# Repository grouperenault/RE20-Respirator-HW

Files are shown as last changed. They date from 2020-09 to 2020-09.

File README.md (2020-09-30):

# RE20-Respirator-HW

All the files in this directory (and its subdirectories) are subject to
the CERN-OHL-S v2 licence.

Copyright Renault SAS 2020.

This source describes Open Hardware and is licensed under the CERN-OHL-S v2.
You may redistribute and modify this documentation and make products
using it under the terms of the CERN-OHL-S v2 (https:/cern.ch/cern-ohl).

This documentation is distributed WITHOUT ANY EXPRESS OR IMPLIED
WARRANTY, INCLUDING OF MERCHANTABILITY, SATISFACTORY QUALITY
AND FITNESS FOR A PARTICULAR PURPOSE. Please see the CERN-OHL-S v2
for applicable conditions.

This repository contains the Design files for the CAD and Electronic elements 
of the RE20-Respirator project.

For a description of the project, please refer to the [Readme of the RE20-Respirator-SW project](https://github.com/grouperenault/RE20-Respirator-SW/blob/master/README.md).

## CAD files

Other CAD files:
01-CASING-V2.1x/CASING.CATProduct
01-CASING-V2.1x/M-034804_--_---_256155.CATPart
01-CASING-V2.1x/M-035808_--_---_256215.CATPart
01-CASING-V2.1x/M-036530_--_---_256219.CATPart
01-CASING-V2.1x/M-03664800_--_---_256156.CATPart
01-CASING-V2.1x/M-036804_--_---_256216.CATPart
01-CASING-V2.1x/M-036820_--_---_256218.CATPart
01-CASING-V2.1x/M-126-4943_--_---_256391.CATPart
01-CASING-V2.1x/M-237-435_--_---_256127.CATPart
01-CASING-V2.1x/M-302-3006_--_---_256133.CATPart
01-CASING-V2.1x/M-468-6327_--_---_256234.CATPart
01-CASING-V2.1x/M-504-4588_--_---_256230.CATPart
01-CASING-V2.1x/M-521655_--_---_256422.CATPart
01-CASING-V2.1x/M-7703002668_--_---_256677.CATPart
01-CASING-V2.1x/M-7703002820_--_---_256847.CATPart
01-CASING-V2.1x/M-7703011320_--_---_256382.CATPart
01-CASING-V2.1x/M-7703027504_--_---_256681.CATPart
01-CASING-V2.1x/M-7703033205_--_---_256309.CATPart
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

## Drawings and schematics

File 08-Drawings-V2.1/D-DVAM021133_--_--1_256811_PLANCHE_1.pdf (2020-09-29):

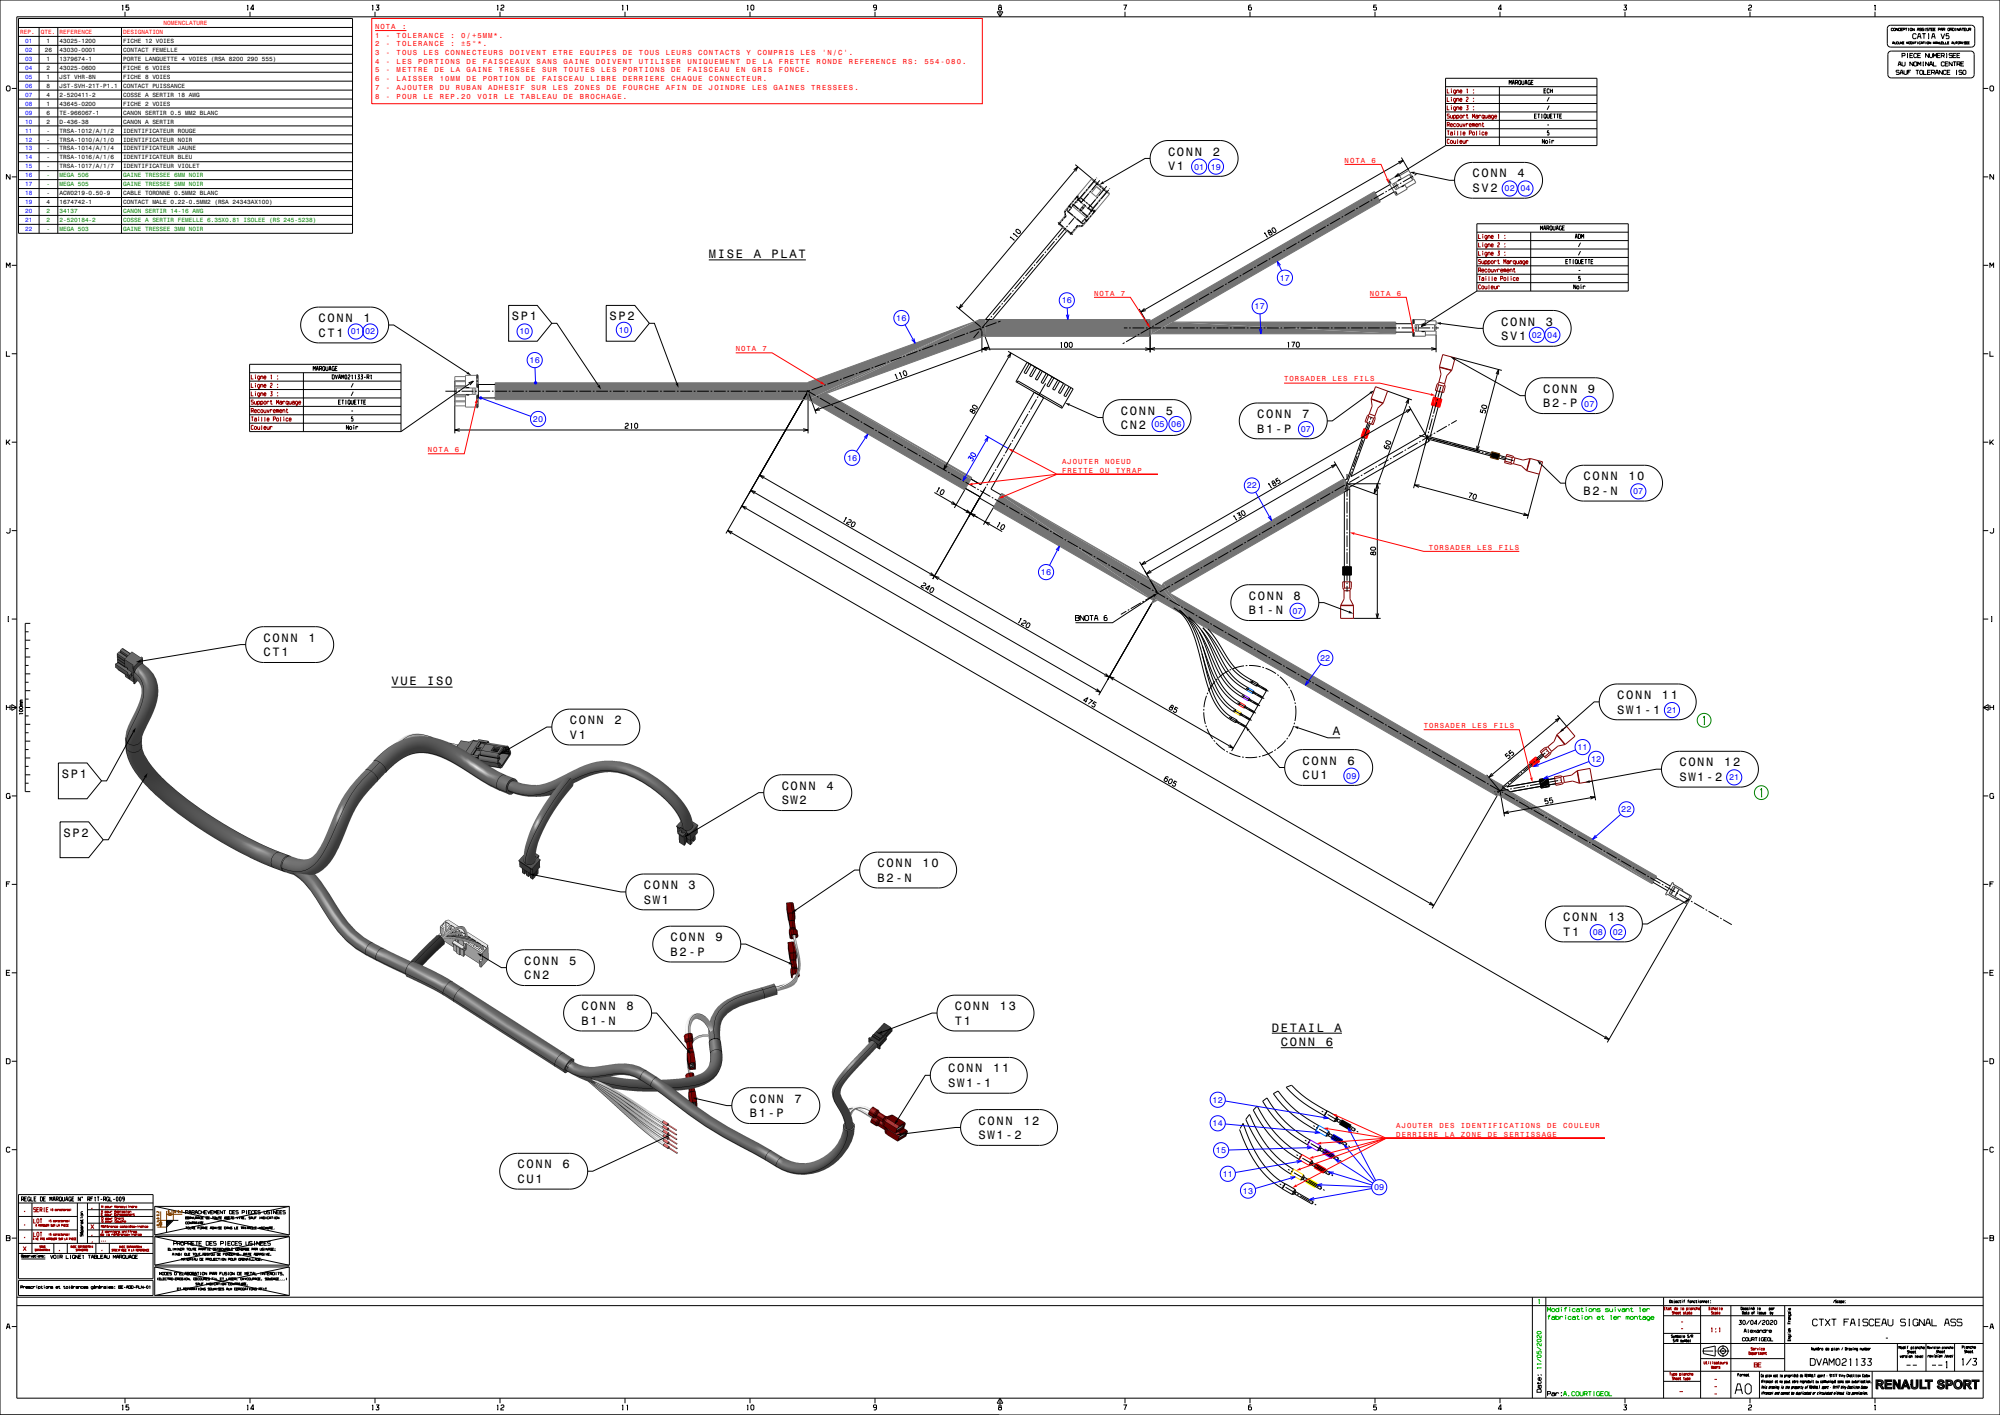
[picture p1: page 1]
MISE A PLAT; CONN 1; CONN 2; CONN 3; CONN 4; CONN 5 CN2 05 06; CONN 6; CONN 11 SW1-1 21; CONN 7 B1-P 07; CONN 9 B2-P 07; CONN 10 B2-N 07; CONN 13; CONN 12 SW1-2 21; CONN 8; NOTA 7; NOTA 6; DETAIL A CONN 6; VUE ISO; CONN 5; CONN 7; CONN 9; CONN 10; CONN 11; CONN 12

NOMENCLATURE | | NOTA : 1 - TOLERANCE : 0/+5MM*. 2 - TOLERANCE : ±5°*. 3 - TOUS LES CONNECTEURS DOIVENT ETRE EQUIPES DE TOUS LEURS CONTACTS Y COMPRIS LES 'N/C'. 4 - LES PORTIONS DE FAISCEAUX SANS GAINE DOIVENT UTILISER UNIQUEMENT DE LA FRETTE RONDE REFERENCE RS: 554-080. 5 - METTRE DE LA GAINE TRESSEE SUR TOUTES LES PORTIONS DE FAISCEAU EN GRIS FONCE. 6 - LAISSER 10MM DE PORTION DE FAISCEAU LIBRE DERRIERE CHAQUE CONNECTEUR. 7 - AJOUTER DU RUBAN ADHESIF SUR LES ZONES DE FOURCHE AFIN DE JOINDRE LES GAINES TRESSEES. 8 - POUR LE REP.20 VOIR LE TABLEAU DE BROCHAGE.

REP. | QTE. | REFERENCE | DESIGNATION
01 | 1 | 43025-1200 | FICHE 12 VOIES
02 | 26 | 43030-0001 | CONTACT FEMELLE
03 | 1 | 1379674-1 | PORTE LANGUETTE 4 VOIES (RSA 8200 290 555)
04 | 2 | 43025-0600 | FICHE 6 VOIES
05 | 1 | JST VHR-8N | FICHE 8 VOIES
06 | 8 | JST-SVH-21T-P1.1 | CONTACT PUISSANCE
07 | 4 | 2-520411-2 | COSSE A SERTIR 18 AWG
08 | 1 | 43645-0200 | FICHE 2 VOIES
09 | 6 | TE-966067-1 | CANON SERTIR 0.5 MM2 BLANC
10 | 2 | D-436-38 | CANON A SERTIR
11 | - | TRSA-1012/A/1/2 | IDENTIFICATEUR ROUGE
12 | - | TRSA-1010/A/1/0 | IDENTIFICATEUR NOIR
13 | - | TRSA-1014/A/1/4 | IDENTIFICATEUR JAUNE
14 | - | TRSA-1016/A/1/6 | IDENTIFICATEUR BLEU
15 | - | TRSA-1017/A/1/7 | IDENTIFICATEUR VIOLET
16 | - | MEGA 506 | GAINE TRESSEE 6MM NOIR
17 | - | MEGA 505 | GAINE TRESSEE 5MM NOIR
18 | - | ACW0219-0.50-9 | CABLE TORONNE 0.5MM2 BLANC
19 | 4 | 1674742-1 | CONTACT MALE 0.22-0.5MM2 (RSA 24343AX100)
20 | 2 | 34137 | CANON SERTIR 14-16 AWG
21 | 2 | 2-520184-2 | COSSE A SERTIR FEMELLE 6.35X0.81 ISOLEE (RS 245-5238)
22 | - | MEGA 503 | GAINE TRESSEE 3MM NOIR

NOTA 7 NOTA 6 16 17

TORSADER LES FILS

AJOUTER NOEUD
FRETTE OU TYRAP

AJOUTER DES IDENTIFICATIONS DE COULEUR
DERRIERE LA ZONE DE SERTISSAGE

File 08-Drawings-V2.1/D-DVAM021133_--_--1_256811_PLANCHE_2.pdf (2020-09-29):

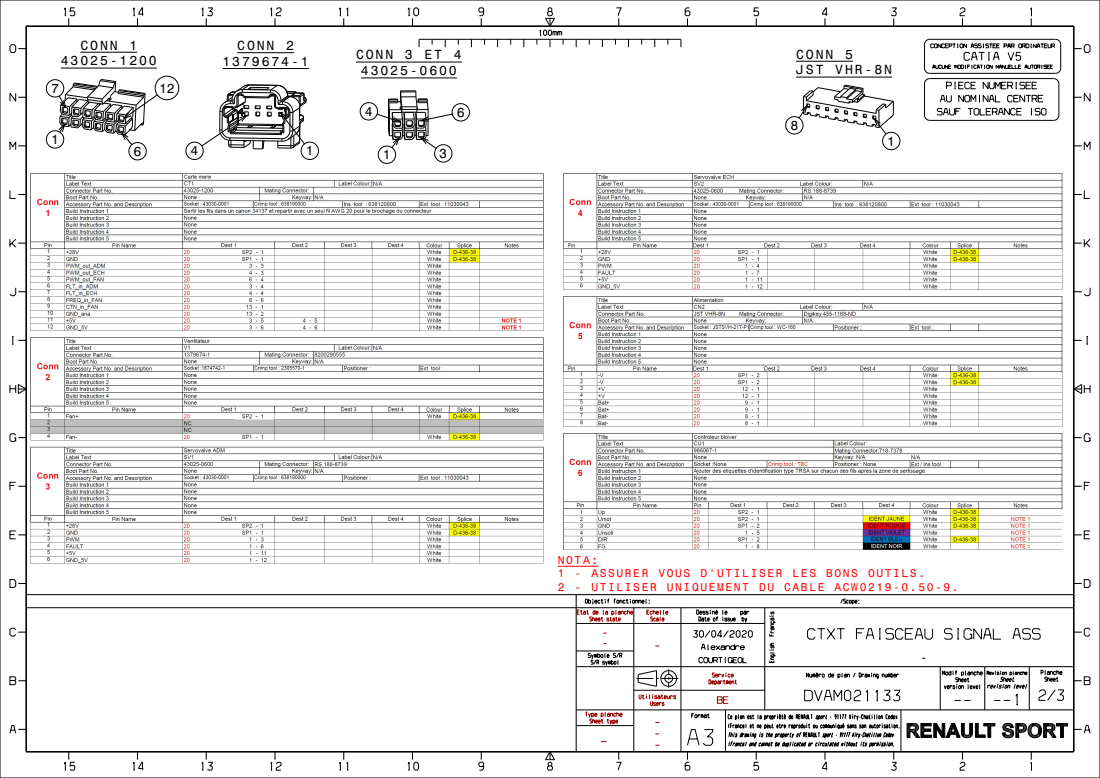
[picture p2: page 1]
CONN 3 ET 4; CONN 1; CONN 5 JST VHR-8N; CONN 2

NOTA:
1 - ASSURER VOUS D'UTILISER LES BONS OUTILS.
2 - UTILISER UNIQUEMENT DU CABLE ACW0219-0.50-9.

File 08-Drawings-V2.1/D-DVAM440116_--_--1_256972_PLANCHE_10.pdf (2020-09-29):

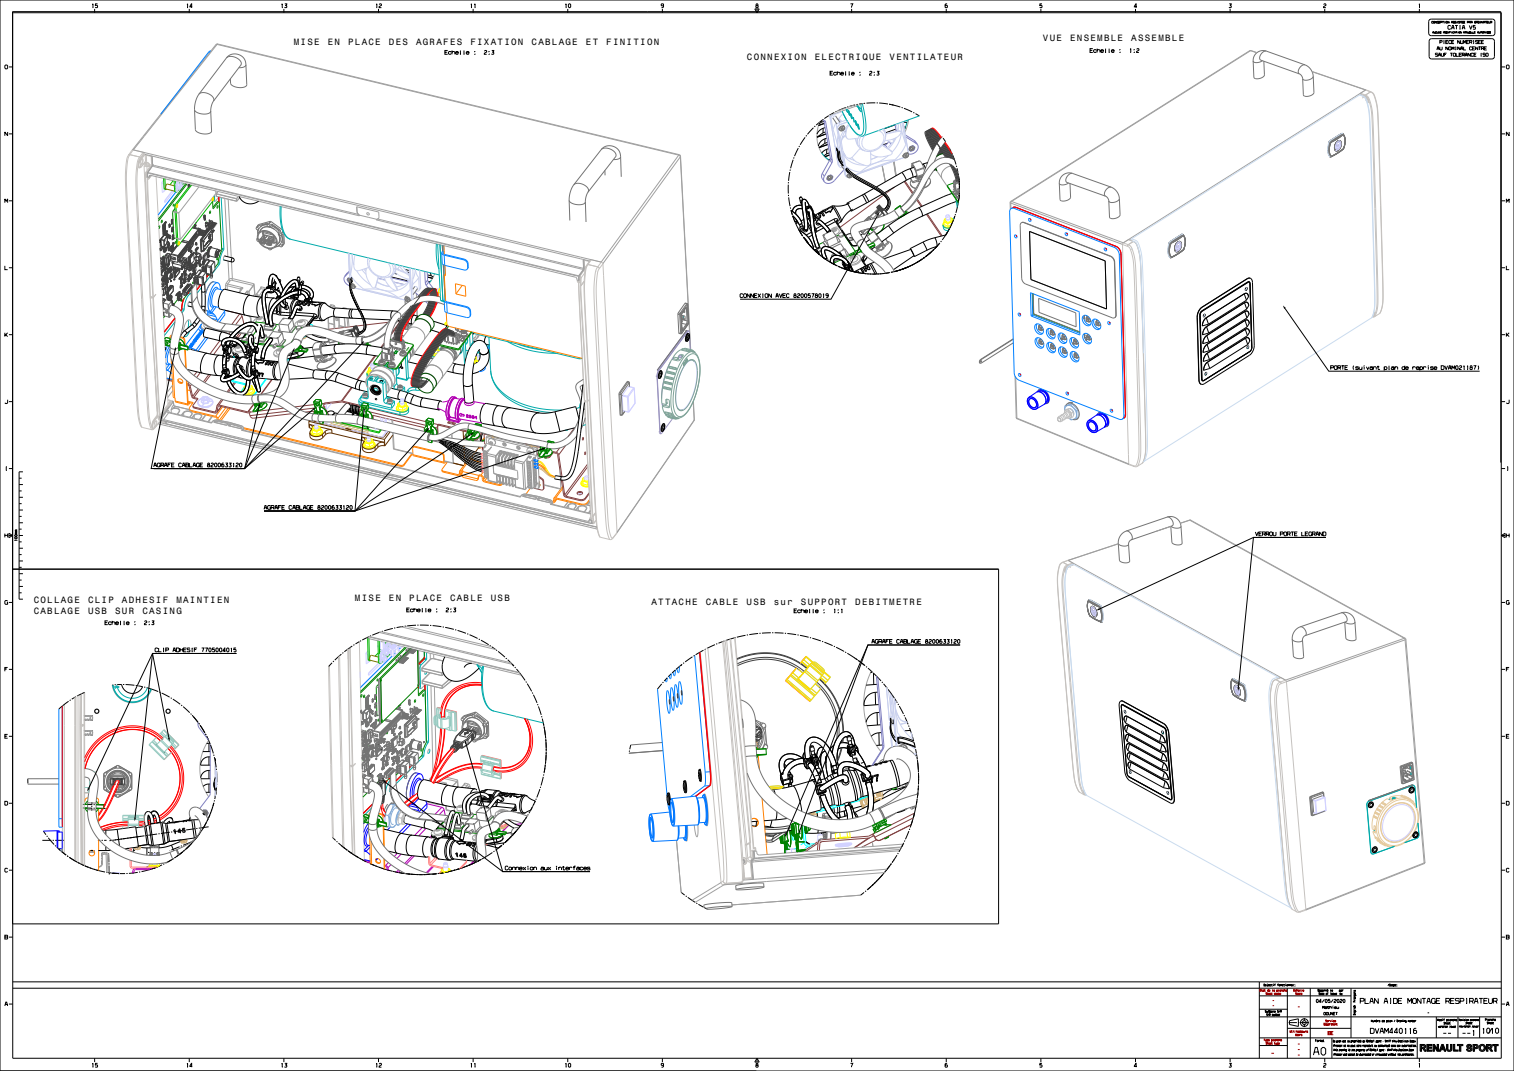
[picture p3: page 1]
COLLAGE CLIP ADHESIF MAINTIEN; MISE EN PLACE CABLE USB

VUE ENSEMBLE ASSEMBLE

MISE EN PLACE DES AGRAFES FIXATION CABLAGE ET FINITION

CONNEXION ELECTRIQUE VENTILATEUR

CABLAGE USB SUR CASING

ATTACHE CABLE USB sur SUPPORT DEBITMETRE

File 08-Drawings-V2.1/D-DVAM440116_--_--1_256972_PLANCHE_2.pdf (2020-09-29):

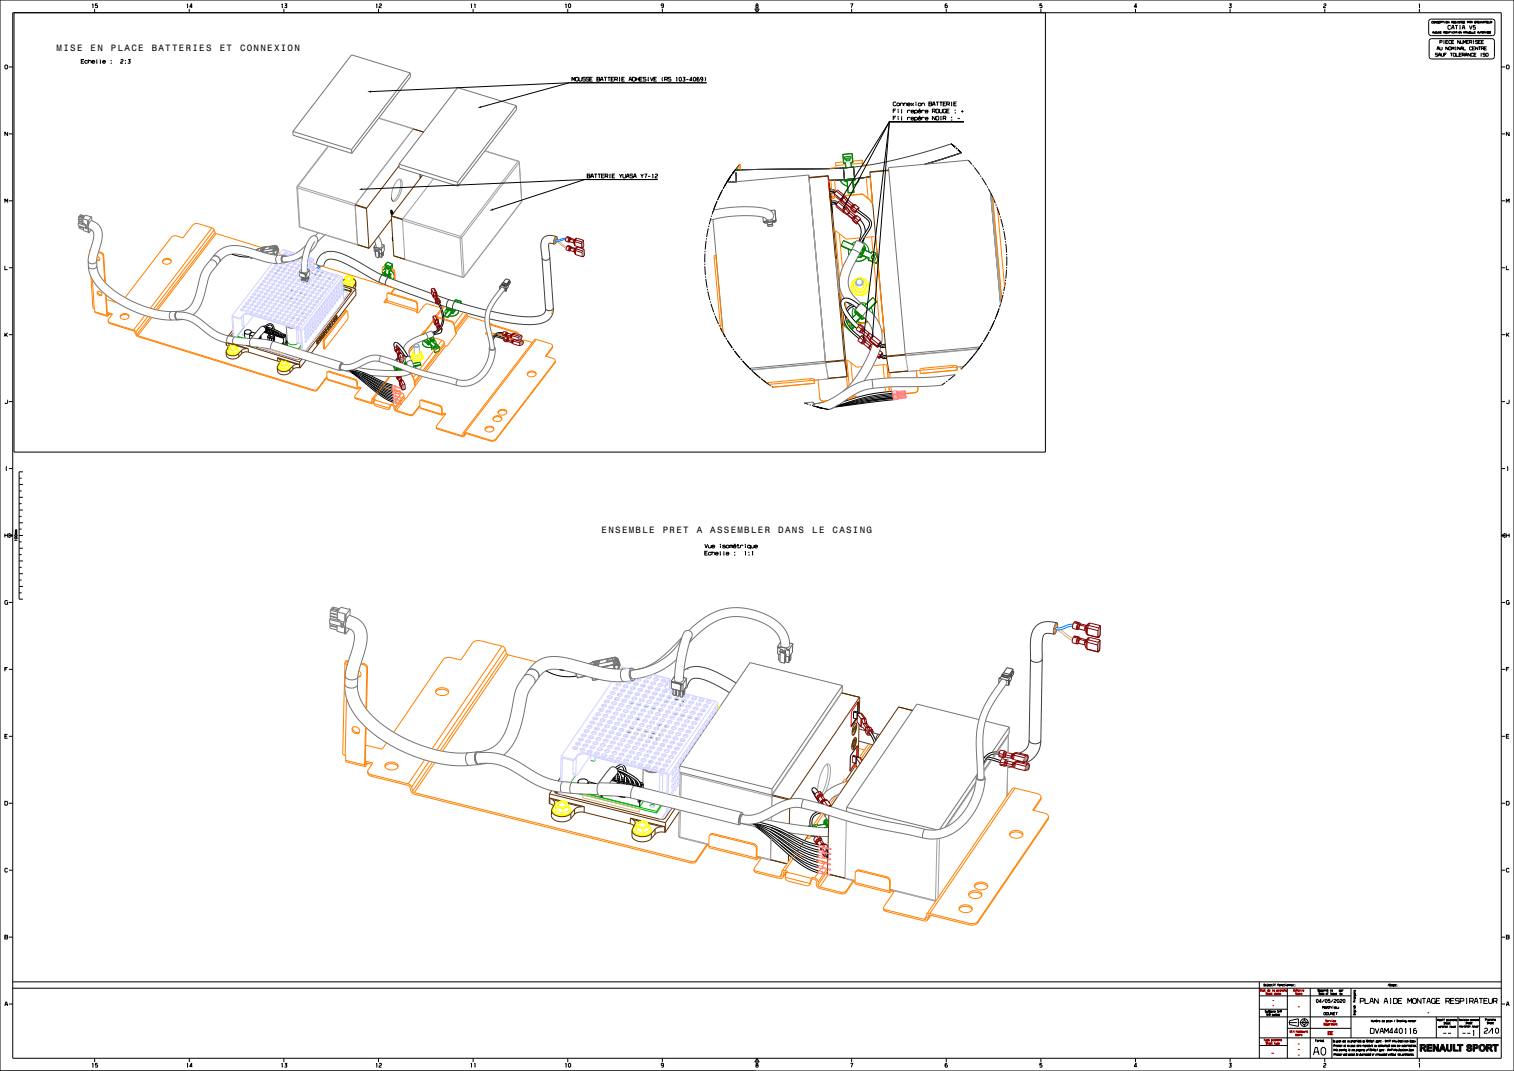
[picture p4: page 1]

MISE EN PLACE BATTERIES ET CONNEXION

ENSEMBLE PRET A ASSEMBLER DANS LE CASING

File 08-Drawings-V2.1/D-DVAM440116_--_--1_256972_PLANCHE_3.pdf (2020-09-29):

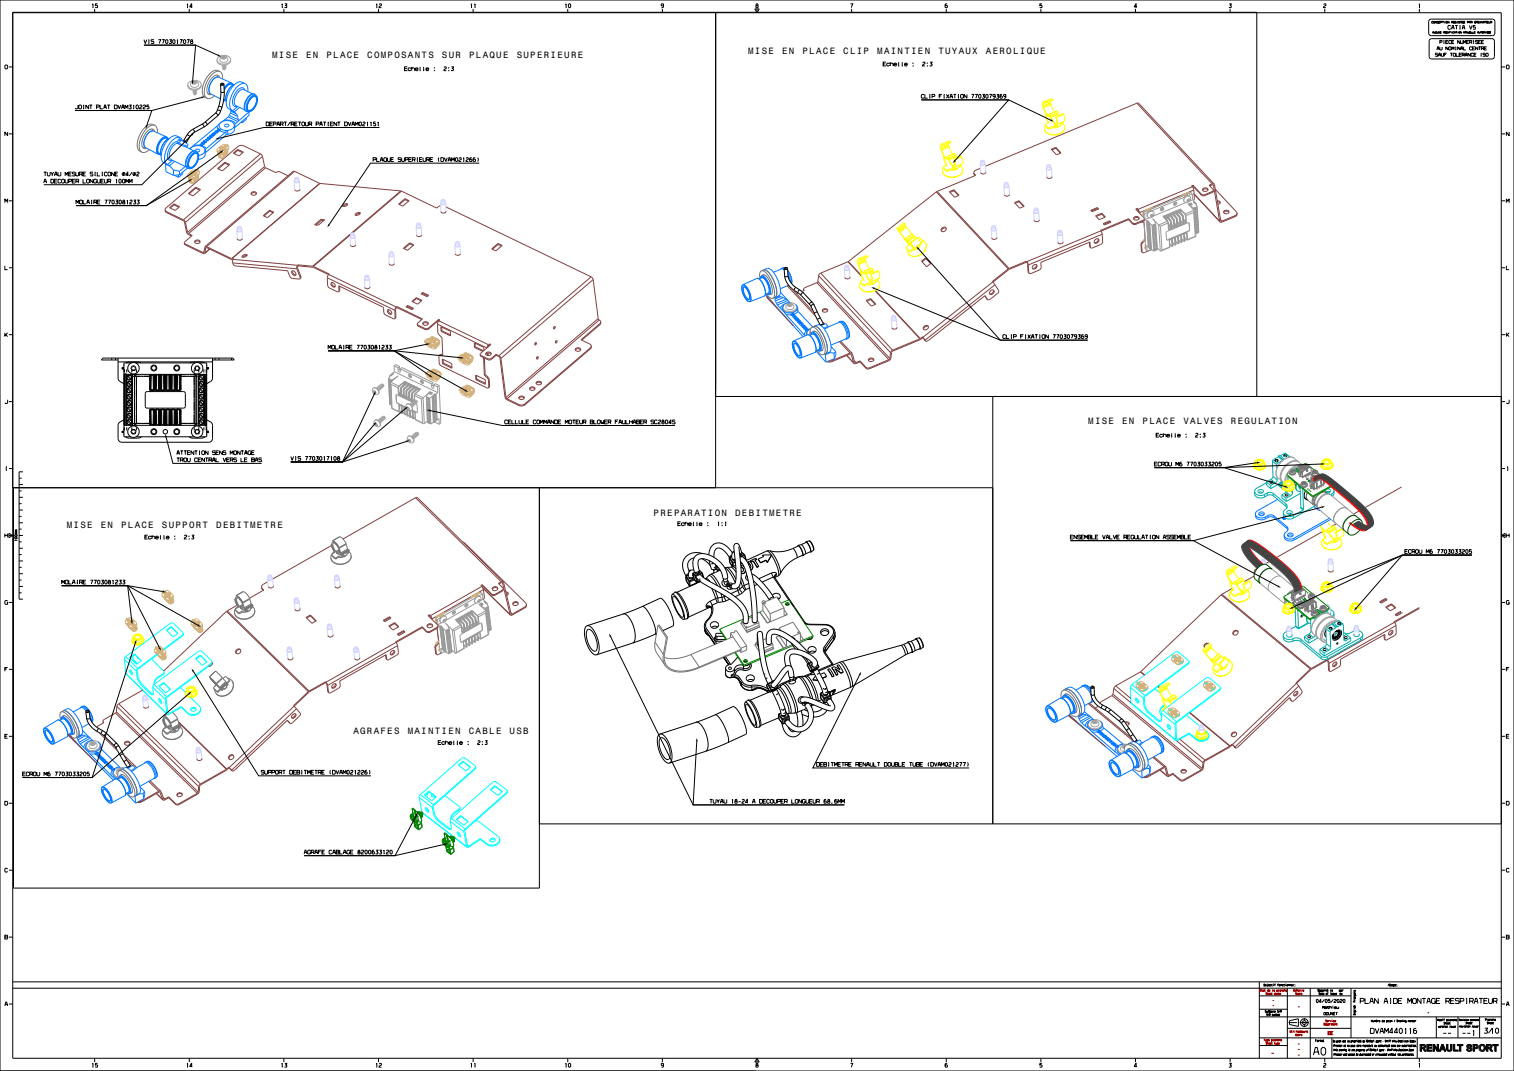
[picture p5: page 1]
PREPARATION DEBITMETRE

MISE EN PLACE CLIP MAINTIEN TUYAUX AEROLIQUE

MISE EN PLACE COMPOSANTS SUR PLAQUE SUPERIEURE

MISE EN PLACE VALVES REGULATION

MISE EN PLACE SUPPORT DEBITMETRE

AGRAFES MAINTIEN CABLE USB

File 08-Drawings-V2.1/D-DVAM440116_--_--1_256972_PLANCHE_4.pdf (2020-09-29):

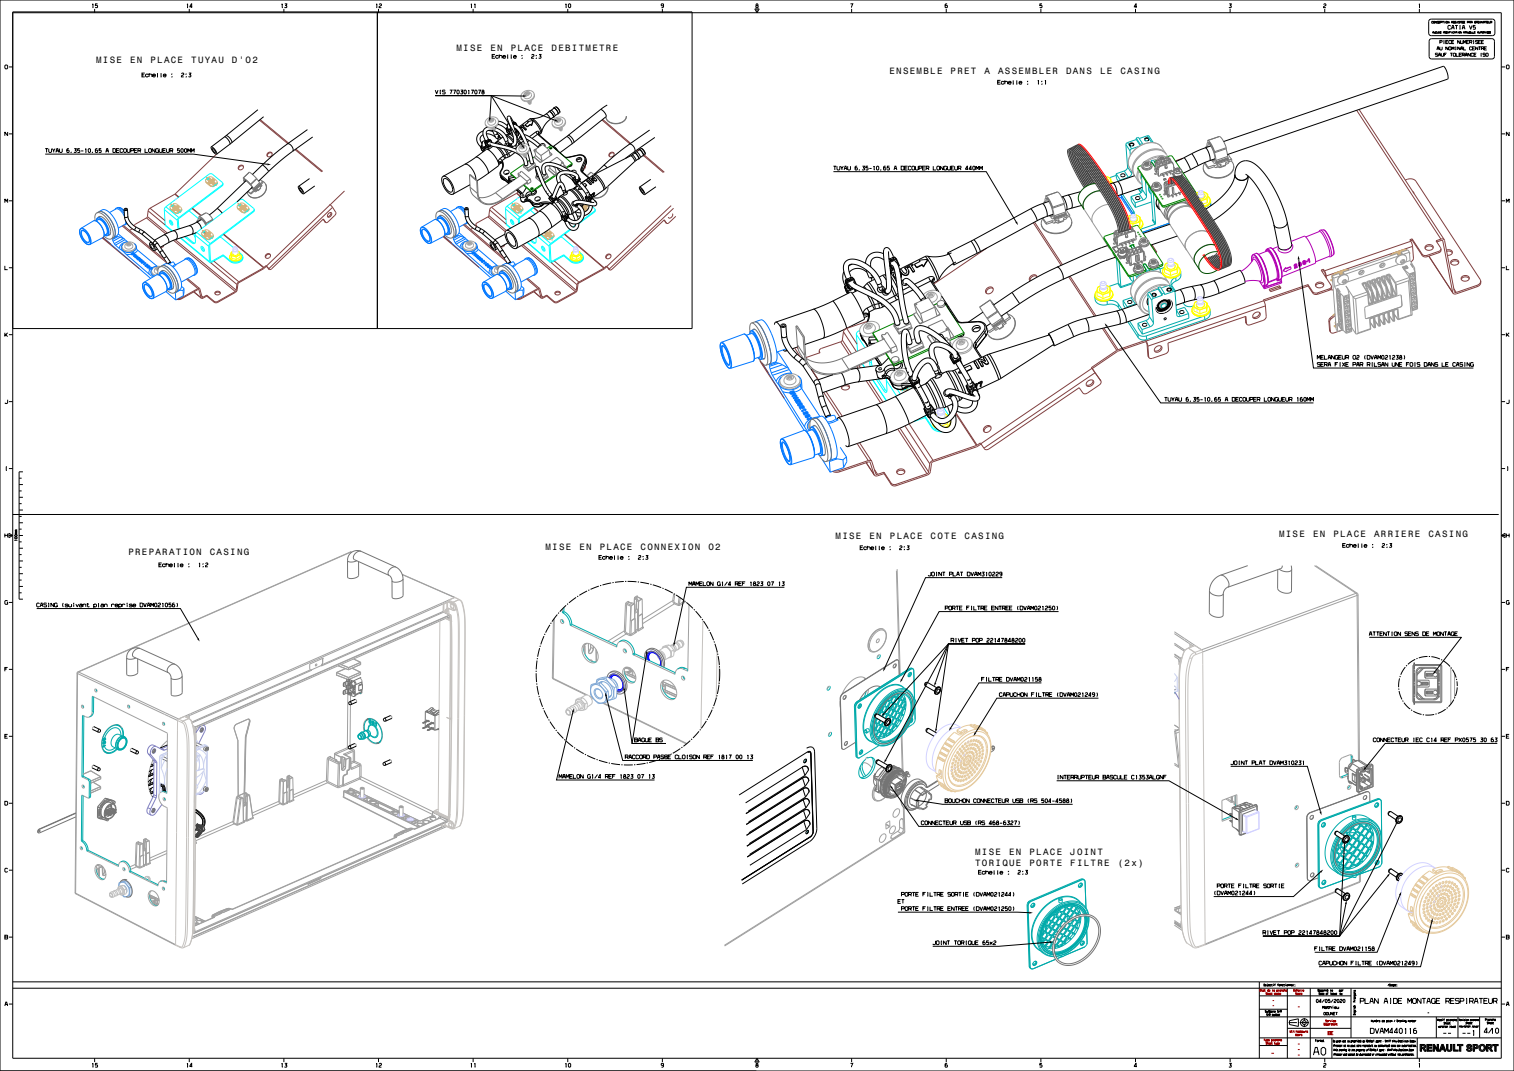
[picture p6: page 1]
PREPARATION CASING; MISE EN PLACE COTE CASING; MISE EN PLACE ARRIERE CASING

MISE EN PLACE DEBITMETRE

MISE EN PLACE TUYAU D'O2

ENSEMBLE PRET A ASSEMBLER DANS LE CASING

MISE EN PLACE CONNEXION O2

MISE EN PLACE JOINT
TORIQUE PORTE FILTRE (2x)

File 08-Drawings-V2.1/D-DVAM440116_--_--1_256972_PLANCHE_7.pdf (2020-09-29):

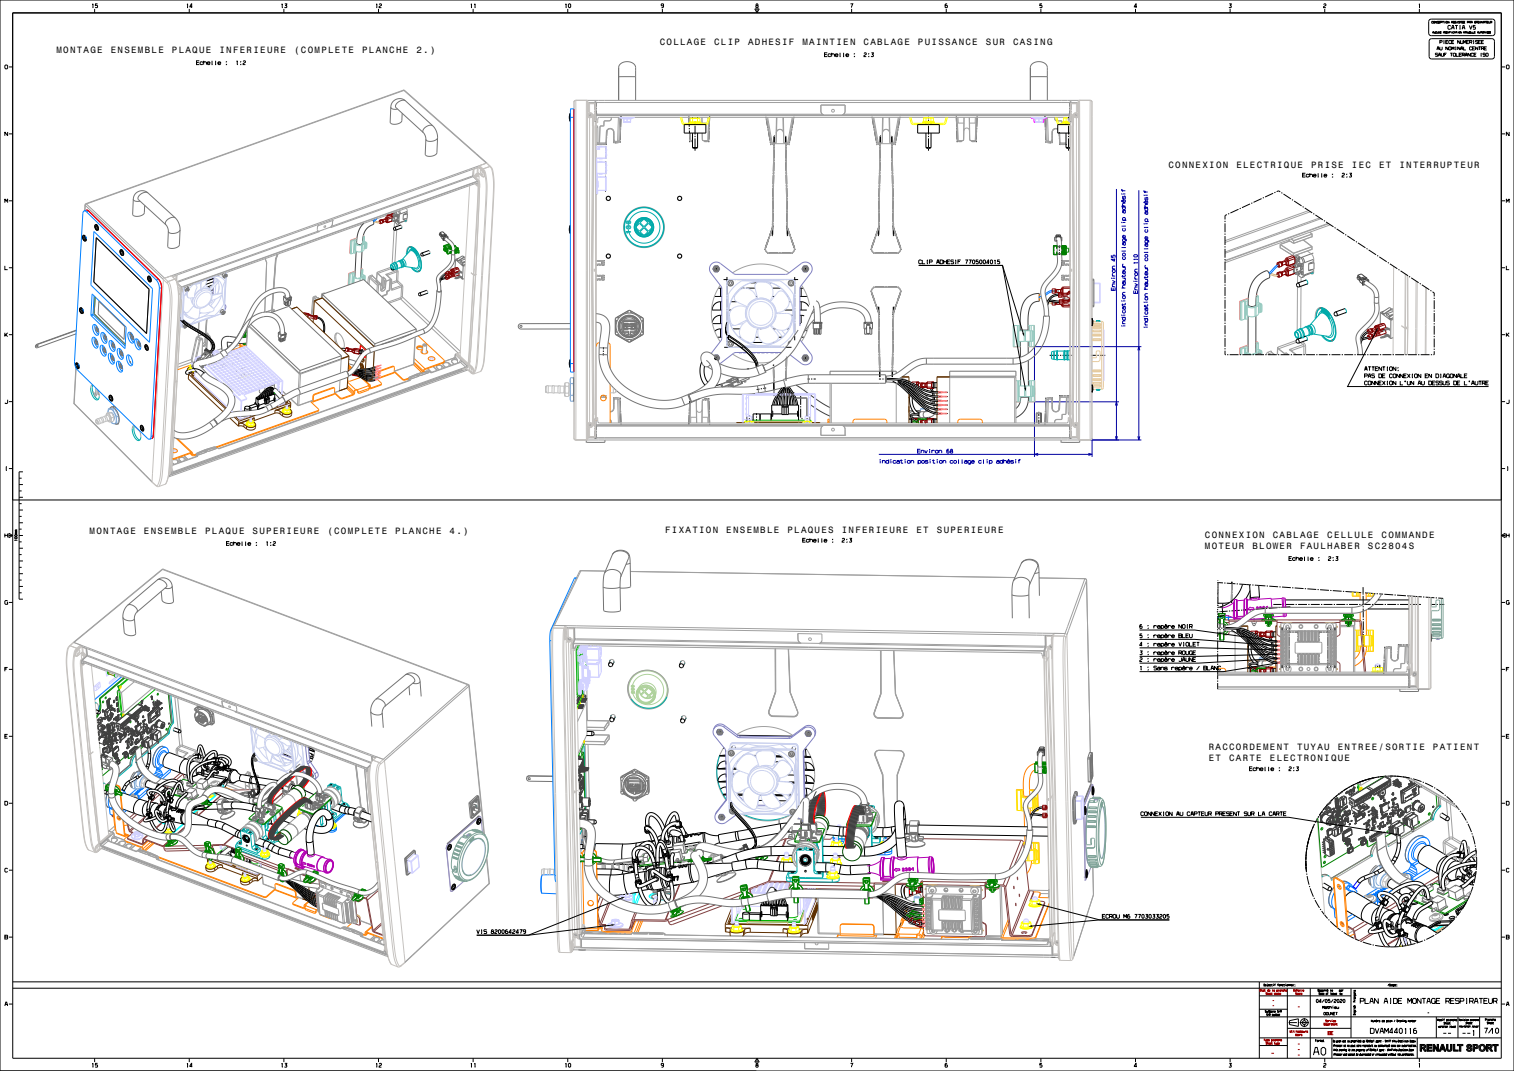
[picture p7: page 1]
MONTAGE ENSEMBLE PLAQUE SUPERIEURE (COMPLETE PLANCHE 4.); FIXATION ENSEMBLE PLAQUES INFERIEURE ET SUPERIEURE

COLLAGE CLIP ADHESIF MAINTIEN CABLAGE PUISSANCE SUR CASING

MONTAGE ENSEMBLE PLAQUE INFERIEURE (COMPLETE PLANCHE 2.)

CONNEXION ELECTRIQUE PRISE IEC ET INTERRUPTEUR

CONNEXION CABLAGE CELLULE COMMANDE
MOTEUR BLOWER FAULHABER SC2804S

RACCORDEMENT TUYAU ENTREE/SORTIE PATIENT
ET CARTE ELECTRONIQUE

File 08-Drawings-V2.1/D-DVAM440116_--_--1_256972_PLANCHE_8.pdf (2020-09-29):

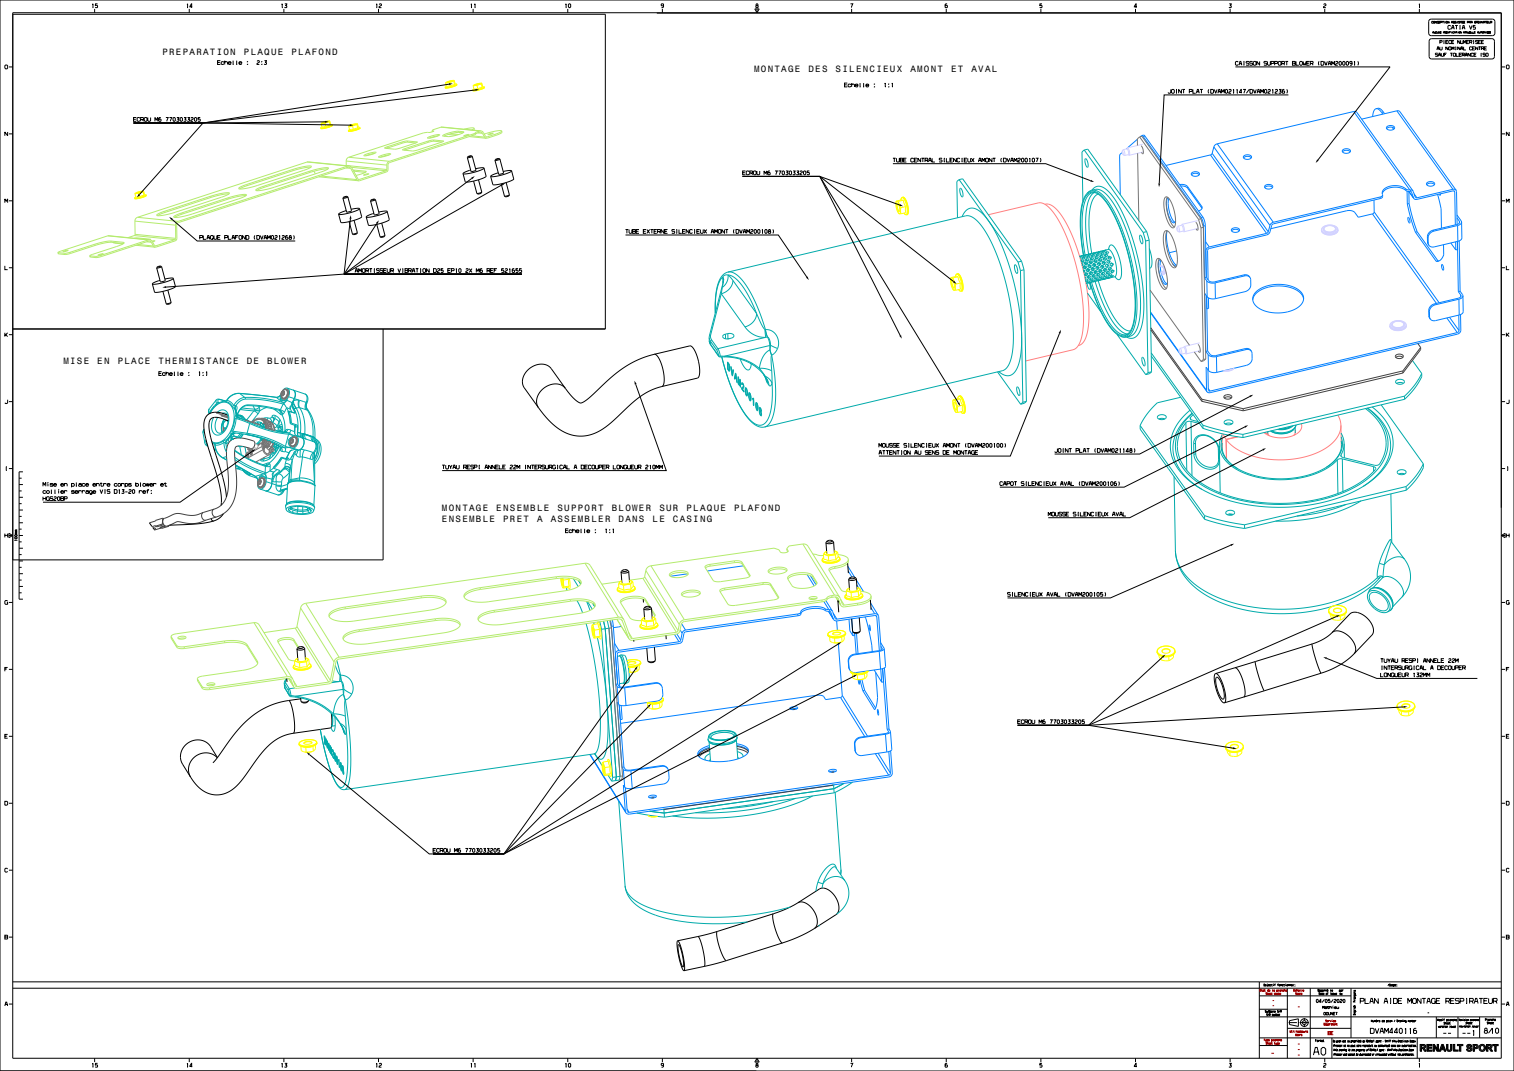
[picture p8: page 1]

PREPARATION PLAQUE PLAFOND

MONTAGE DES SILENCIEUX AMONT ET AVAL

MISE EN PLACE THERMISTANCE DE BLOWER

MONTAGE ENSEMBLE SUPPORT BLOWER SUR PLAQUE PLAFOND
ENSEMBLE PRET A ASSEMBLER DANS LE CASING

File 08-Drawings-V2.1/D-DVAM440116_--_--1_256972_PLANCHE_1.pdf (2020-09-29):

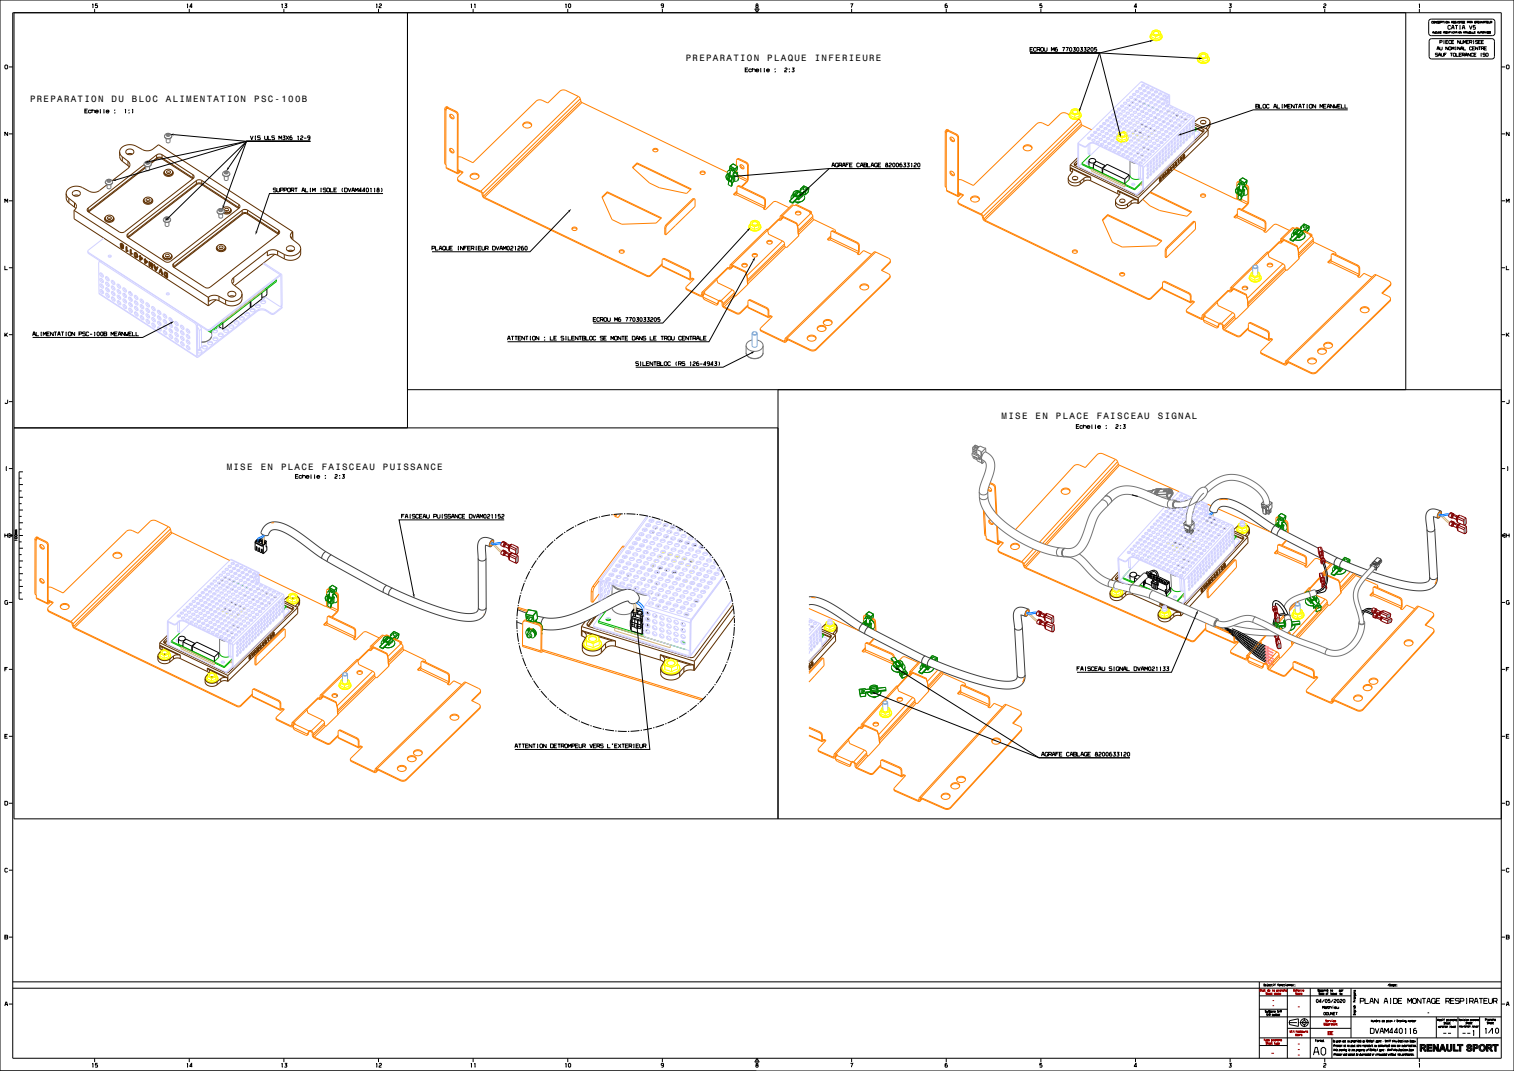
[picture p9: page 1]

PREPARATION PLAQUE INFERIEURE

PREPARATION DU BLOC ALIMENTATION PSC-100B

MISE EN PLACE FAISCEAU SIGNAL

MISE EN PLACE FAISCEAU PUISSANCE

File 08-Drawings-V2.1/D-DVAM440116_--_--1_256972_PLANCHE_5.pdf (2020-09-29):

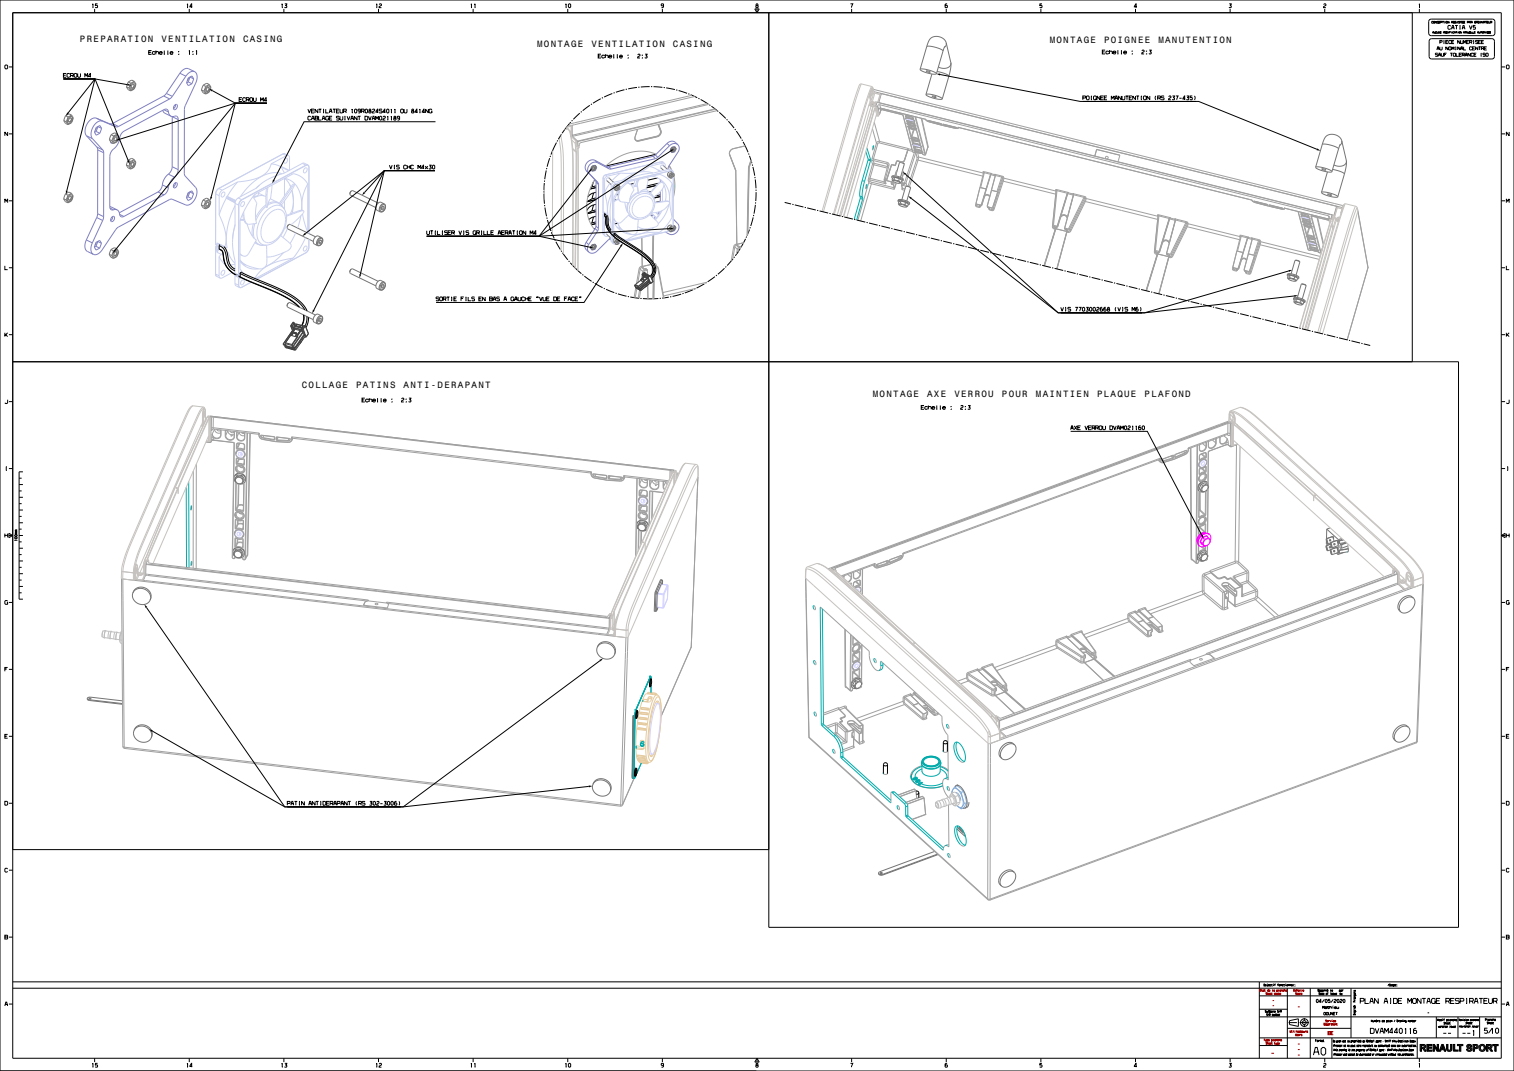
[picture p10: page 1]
PREPARATION VENTILATION CASING; MONTAGE VENTILATION CASING

MONTAGE POIGNEE MANUTENTION

COLLAGE PATINS ANTI-DERAPANT

MONTAGE AXE VERROU POUR MAINTIEN PLAQUE PLAFOND

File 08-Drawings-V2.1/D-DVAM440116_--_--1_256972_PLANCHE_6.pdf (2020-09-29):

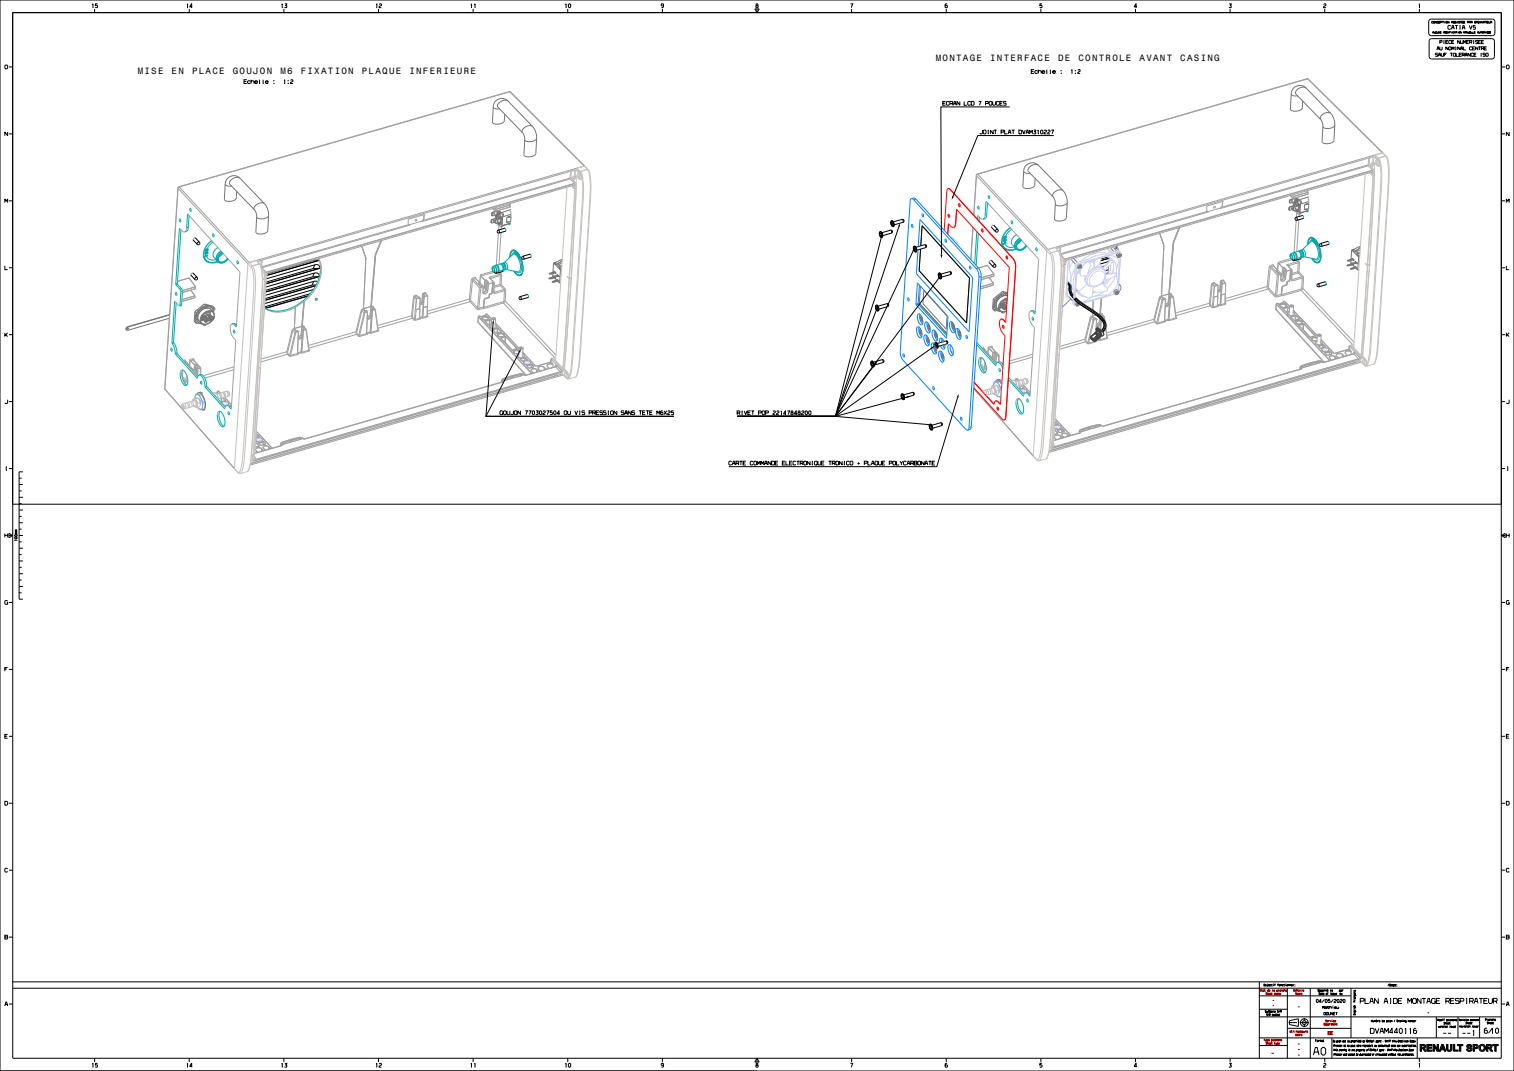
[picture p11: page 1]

MONTAGE INTERFACE DE CONTROLE AVANT CASING

MISE EN PLACE GOUJON M6 FIXATION PLAQUE INFERIEURE

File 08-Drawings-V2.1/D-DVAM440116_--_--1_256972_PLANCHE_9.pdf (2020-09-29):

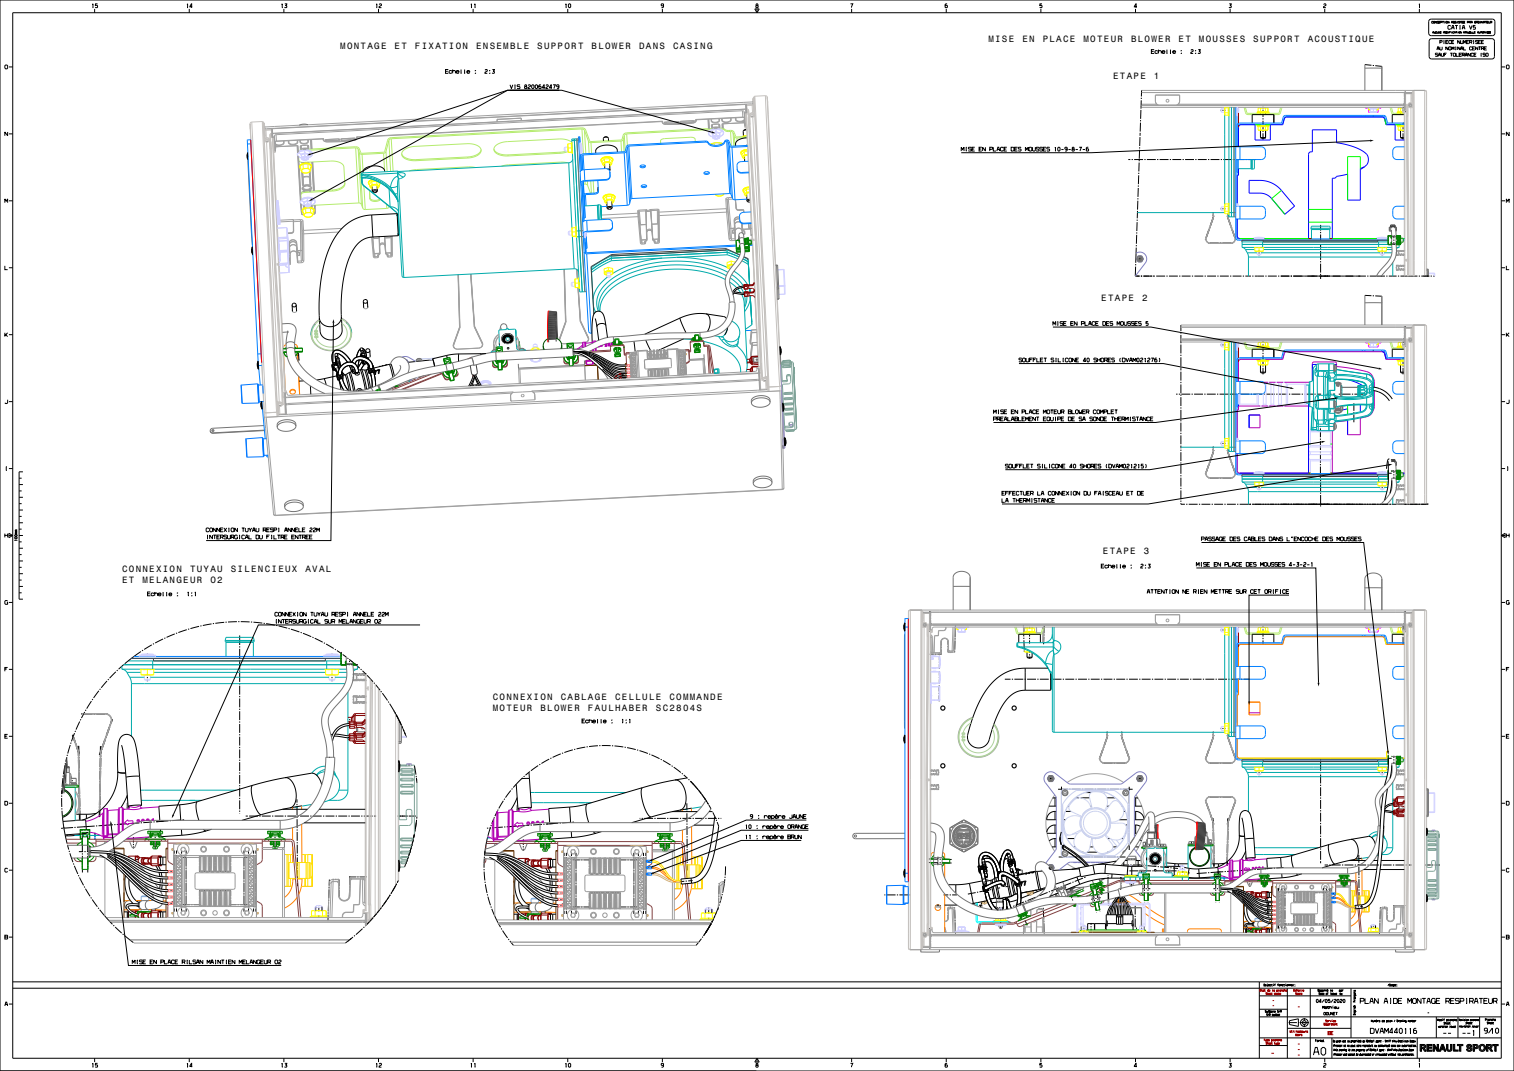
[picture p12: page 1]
ETAPE 1; ETAPE 2; ETAPE 3

MISE EN PLACE MOTEUR BLOWER ET MOUSSES SUPPORT ACOUSTIQUE

MONTAGE ET FIXATION ENSEMBLE SUPPORT BLOWER DANS CASING

CONNEXION TUYAU SILENCIEUX AVAL
ET MELANGEUR O2

CONNEXION CABLAGE CELLULE COMMANDE
MOTEUR BLOWER FAULHABER SC2804S
